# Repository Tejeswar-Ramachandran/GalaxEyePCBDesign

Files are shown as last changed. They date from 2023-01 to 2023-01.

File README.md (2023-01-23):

# GalaxEyePCBDesign
Internship Task for GalaxEye Space

GALAXEYE SPACE

INTERNSHIP TASK

Problem Statement:
1. You need to be able to convert inputs from up to 4 different digital I/O pins and get an output of 24 GPIO pins with a different logic level.
2. You need to design a neatly labeled schematic of this design and also generate a BOM with links to in-stock parts

Solution:

The Microcontroller will send out values at 3.3V level, from 4 different digital I/O pins. The output from these pins are passed through a level shifter to convert them to a different logic level. Once the logic level has been changed, the 4 output values are passed through 4 8 bit SIPO shift registers to obtain a total of 32 bits as output. Finally, 2 bits from each SIPO shift register were grounded to shorten the output to just 24 bits.

Assumptions:
1.	The Microcontroller input is directly given by the user. The Microcontroller reads it and directly passes it on to the Level Shifter without the requirement of any external processing.
2.	2 Bits from each SIPO Shift register were chosen and connected to the ground. An alternative would be to connect 8 bits from an entire shift register to bring down the output to 24 bits instead of 32 bits, but then we would have to ignore an input completely out of the 4 input bits.

Components:
1.	SIPO Shift Register – 74HC595D
2.	3.3V to 5V Logic Level Converter – Sparkfun Bi-Directional Logic Level Converter.

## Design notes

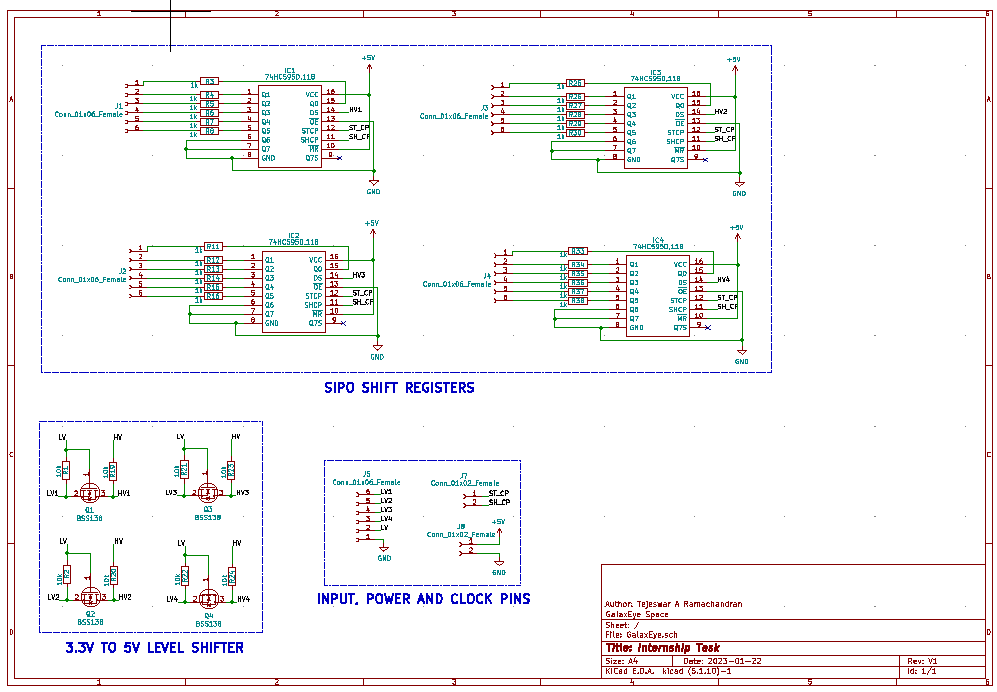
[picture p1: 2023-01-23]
Schematic.png

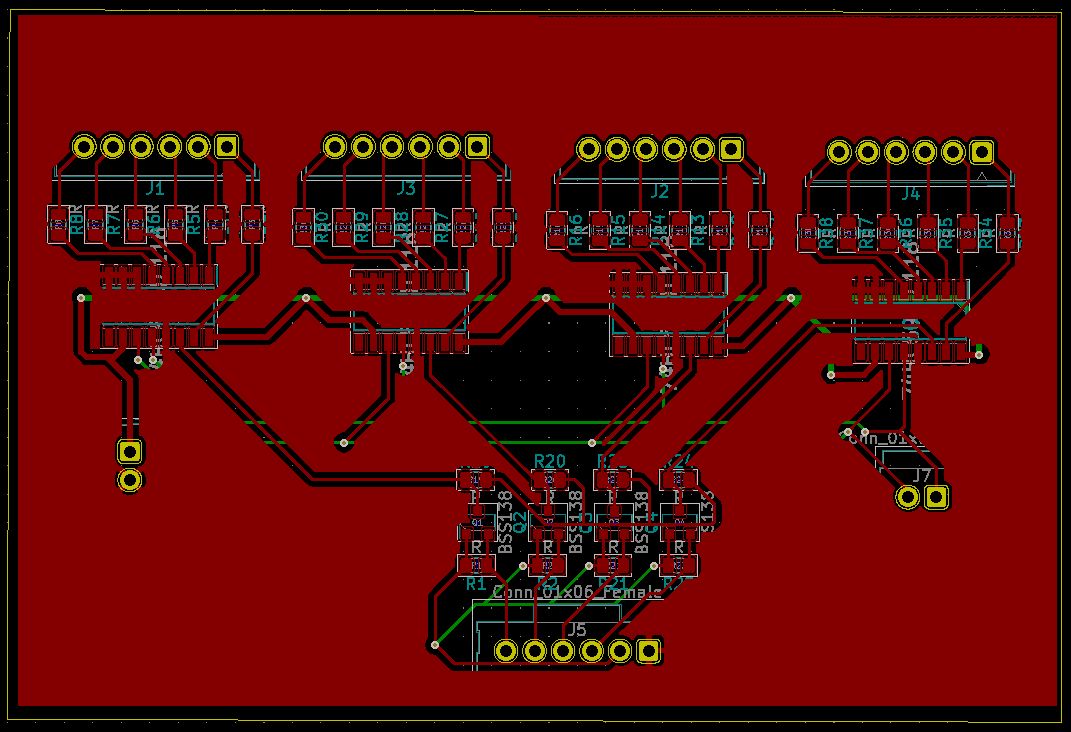
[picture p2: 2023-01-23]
Layout.png

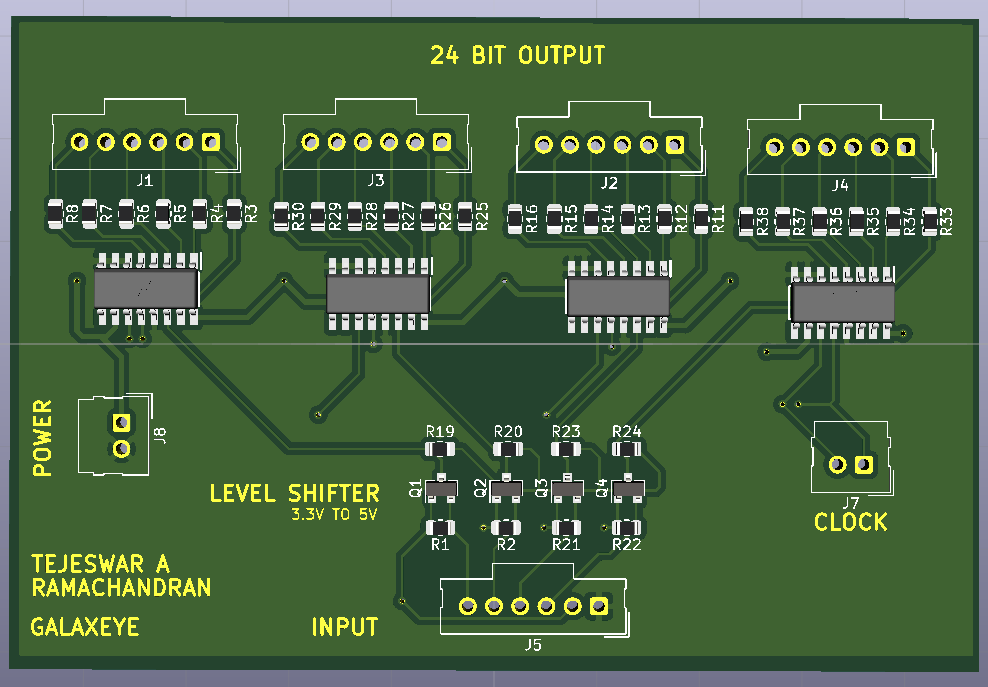
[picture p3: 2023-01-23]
3D View.png

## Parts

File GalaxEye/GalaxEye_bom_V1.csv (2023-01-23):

Component | Description | Part | References | Value | Footprint | Quantity Per PCB | Datasheet | Mouser Price/Stock | Mouser Part Number | Manufacturer_Name | Arrow Part Number | Height | Arrow Price/Stock | Manufacturer_Part_Number
1 | 8-bit serial-in, serial or parallel-out shift register with output latches 3-state | 74HC595D,118 | IC1 IC2 IC3 IC4 | 74HC595D,118 | SOIC127P600X175-16N | 4 | https://assets.nexperia.com/documents/data-sheet/74HC_HCT595.pdf | https://www.mouser.co.uk/ProductDetail/Nexperia/74HC595D118?qs=P62ublwmbi8l0ry%252BN2uyHg%3D%3D | 771-74HC595D-T | Nexperia | 74HC595D,118 | 1.75 | https://www.arrow.com/en/products/74hc595d118/nexperia?region=europe | 74HC595D,118
2 | Generic connector, single row, 01x02, script generated (kicad-library-utils/schlib/autogen/connector/) | Conn_01x02_Female | J7 J8 | Conn_01x02_Female | Molex_SL_171971-0002_1x02_P2.54mm_Vertical | 2 | ~
3 | Generic connector, single row, 01x06, script generated (kicad-library-utils/schlib/autogen/connector/) | Conn_01x06_Female | J1 J2 J3 J4 J5 | Conn_01x06_Female | Molex_SL_171971-0006_1x06_P2.54mm_Vertical | 5 | ~
4 | 50V Vds, 0.22A Id, N-Channel MOSFET, SOT-23 | BSS138 | Q1 Q2 Q3 Q4 | BSS138 | SOT-23 | 4 | https://www.onsemi.com/pub/Collateral/BSS138-D.PDF
5 | Resistor | R | R3 R4 R5 R6 R7 R8 R11 R12 R13 R14 R15 R16 R25 R26 R27 R28 R29 R30 R33 R34 R35 R36 R37 R38 | 1k | R_0805_2012Metric | 24 | ~
6 | Resistor | R | R1 R2 R19 R20 R21 R22 R23 R24 | 10k | R_0805_2012Metric | 8 | ~
Component Groups: | 6
Component Count: | 47
Fitted Components: | 47
Number of PCBs: | 1
Total components: | 47
Schematic Version: | V1
Schematic Date: | 2023-01-22
PCB Variant: | udefault
BoM Date: | 01/23/23 21:36:17
Schematic Source: | GalaxEye.sch
KiCad Version: | Eeschema (5.1.10)-1

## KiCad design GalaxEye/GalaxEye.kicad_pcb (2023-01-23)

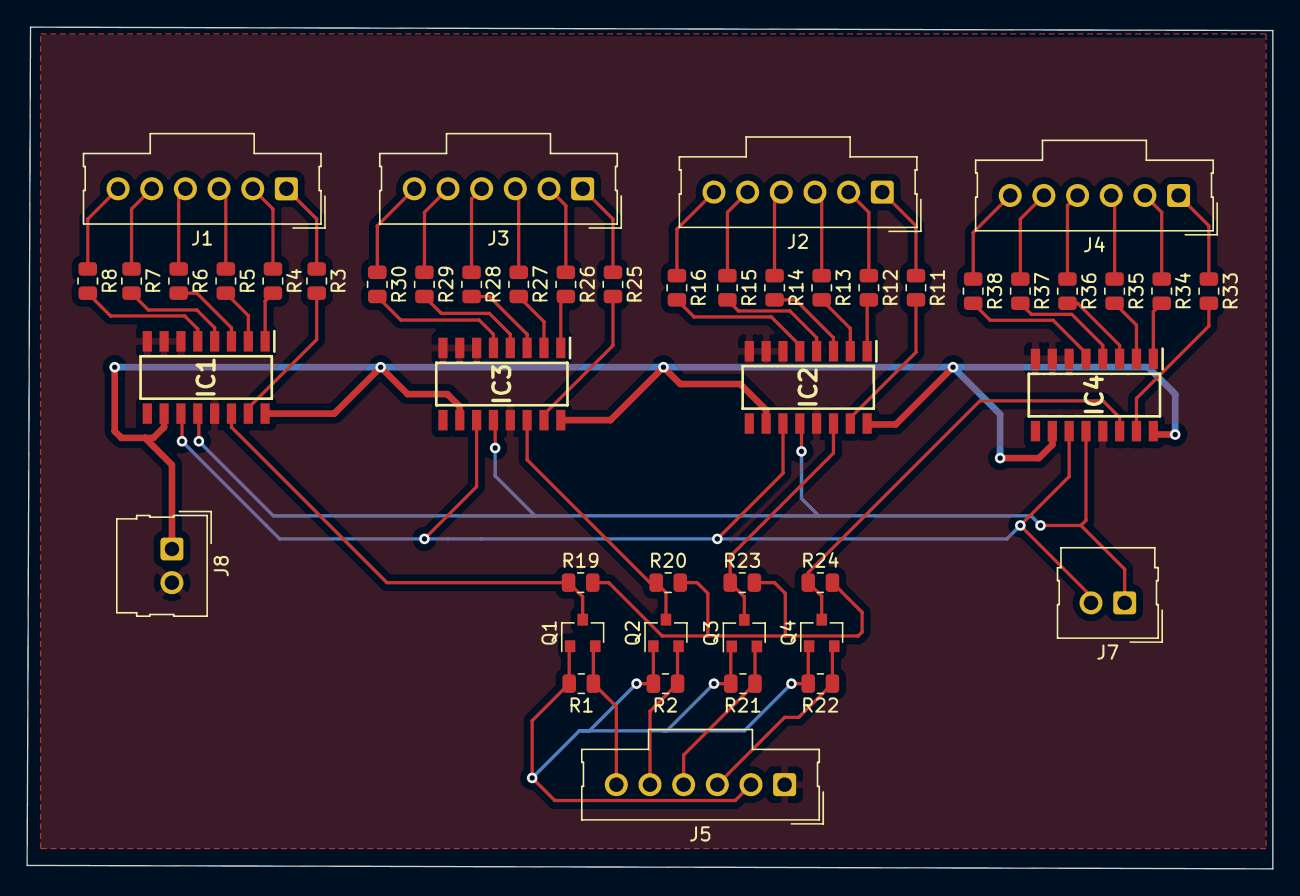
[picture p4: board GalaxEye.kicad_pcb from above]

Board: 2 copper layers, 94.0 x 63.5 mm, 47 parts (0 on the bottom side), 62 nets.

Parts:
IC1, IC2, IC3, IC4: 74HC595D,118; SOIC127P600X175-16N
J1, J2, J3, J4, J5: Conn_01x06_Female; Molex_SL_171971-0006_1x06_P2.54mm_Vertical
J7, J8: Conn_01x02_Female; Molex_SL_171971-0002_1x02_P2.54mm_Vertical
Q1, Q2, Q3, Q4: BSS138; SOT-23
R1, R2, R3, R4, R5, R6, R7, R8, R11, R12, R13, R14, R15, R16, R19, R20, R21, R22, R23, R24, R25, R26, R27, R28, R29, R30, R33, R34, R35, R36, R37, R38: R; R_0805_2012Metric

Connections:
+5V: IC1.10, IC1.16, IC2.10, IC2.16, IC3.10, IC3.16, IC4.10, IC4.16, J8.1
/HV: R19.2, R20.2, R23.2, R24.2
/HV1: IC1.14, Q1.3, R19.1
/HV2: IC3.14, Q2.3, R20.1
/HV3: IC2.14, Q3.3, R23.1
/HV4: IC4.14, Q4.3, R24.1
/LV: J5.2, Q1.1, Q2.1, Q3.1, Q4.1, R1.2, R2.2, R21.2, R22.2
/LV1: J5.6, Q1.2, R1.1
/LV2: J5.5, Q2.2, R2.1
/LV3: J5.4, Q3.2, R21.1
/LV4: J5.3, Q4.2, R22.1
/SH_CP: IC1.11, IC2.11, IC3.11, IC4.11, J7.2
/ST_CP: IC1.12, IC2.12, IC3.12, IC4.12, J7.1
GND: IC1.6, IC1.7, IC1.8, IC1.13, IC2.6, IC2.7, IC2.8, IC2.13, IC3.6, IC3.7, IC3.8, IC3.13, IC4.6, IC4.7, IC4.8, IC4.13, J5.1, J8.2
unnamed: IC1.1, R4.2
unnamed: IC1.2, R5.2
unnamed: IC1.3, R6.2
unnamed: IC1.4, R7.2
unnamed: IC1.5, R8.2
unnamed: IC1.15, R3.2
unnamed: IC2.1, R12.2
unnamed: IC2.2, R13.2
unnamed: IC2.3, R14.2
unnamed: IC2.4, R15.2
unnamed: IC2.5, R16.2
unnamed: IC2.15, R11.2
unnamed: IC3.1, R26.2
unnamed: IC3.2, R27.2
unnamed: IC3.3, R28.2
unnamed: IC3.4, R29.2
unnamed: IC3.5, R30.2
unnamed: IC3.15, R25.2
unnamed: IC4.1, R34.2
unnamed: IC4.2, R35.2
unnamed: IC4.3, R36.2
unnamed: IC4.4, R37.2
unnamed: IC4.5, R38.2
unnamed: IC4.15, R33.2
unnamed: J1.1, R3.1
unnamed: J1.2, R4.1
unnamed: J1.3, R5.1
unnamed: J1.4, R6.1
unnamed: J1.5, R7.1
unnamed: J1.6, R8.1
unnamed: J2.1, R11.1
unnamed: J2.2, R12.1
unnamed: J2.3, R13.1
unnamed: J2.4, R14.1
unnamed: J2.5, R15.1
unnamed: J2.6, R16.1
unnamed: J3.1, R25.1
unnamed: J3.2, R26.1
unnamed: J3.3, R27.1
unnamed: J3.4, R28.1
unnamed: J3.5, R29.1
unnamed: J3.6, R30.1
unnamed: J4.1, R33.1
unnamed: J4.2, R34.1
unnamed: J4.3, R35.1
unnamed: J4.4, R36.1
unnamed: J4.5, R37.1
unnamed: J4.6, R38.1
